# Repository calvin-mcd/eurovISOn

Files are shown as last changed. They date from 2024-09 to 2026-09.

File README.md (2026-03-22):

# eurovISOn
 
40% keyboard designed by some weird Europeans from the 40s discord. It's a qaz-like with special character cluster, exploded ISO with rgb (because why not!?), a macro column to the left and rotary and oled support. It sports a rp2040 and uses a pico Daughterboard for the usb port.

The case is being designed by Haizeus from [haikey](https://www.haikey.design/) and is inspired by the float65. Case design is not finished.

Disclaimer: 
**this is a work in progress project, do not use any of its files**

## Layout

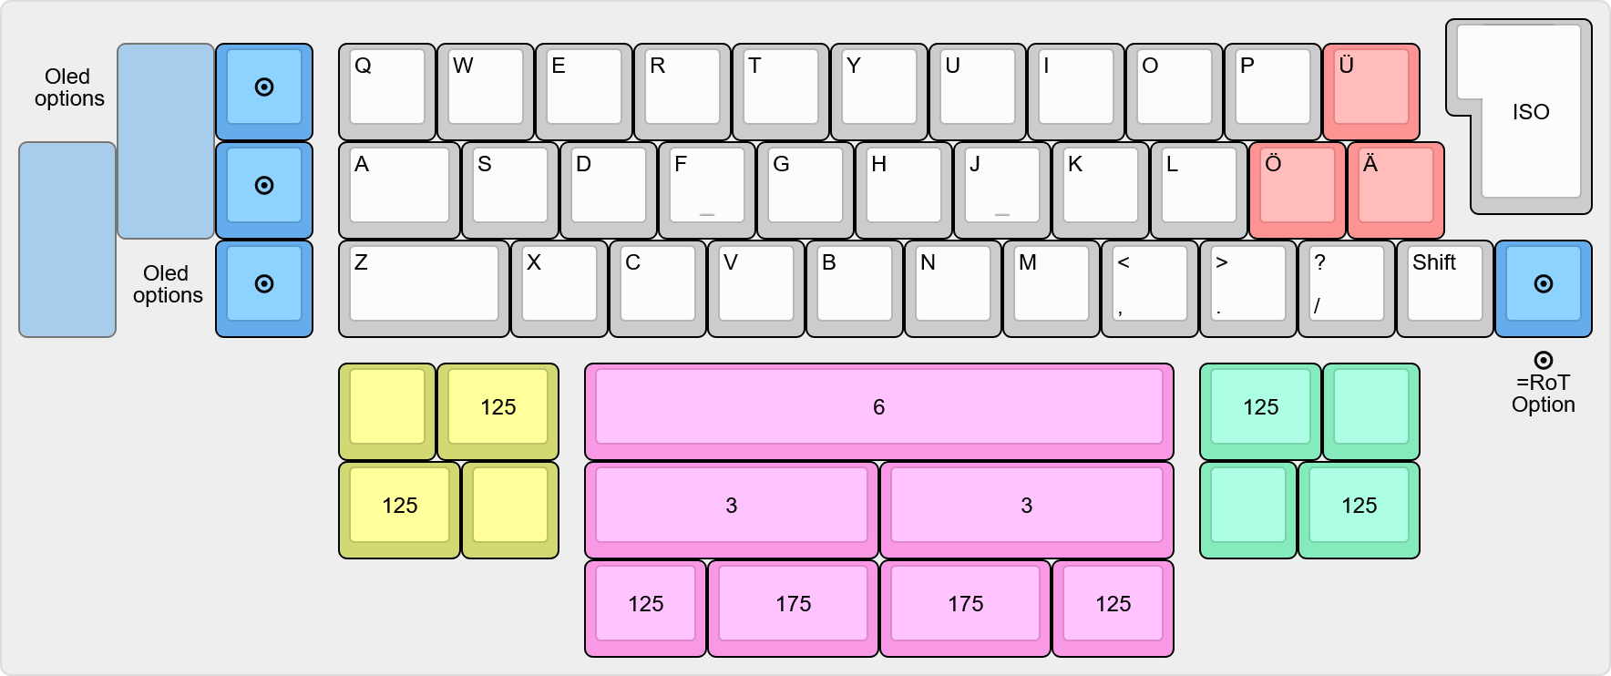
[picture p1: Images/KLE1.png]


[Link](https://www.keyboard-layout-editor.com/#/gists/c5cb8d03115bd811b00f9896965940d2)
**the KLE gist is outdated, refer to the screen above**

## Pictures

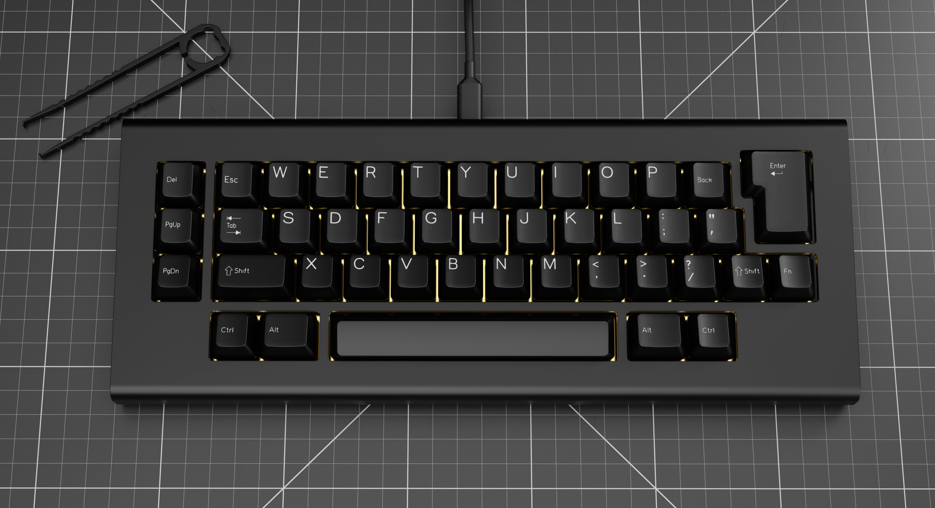
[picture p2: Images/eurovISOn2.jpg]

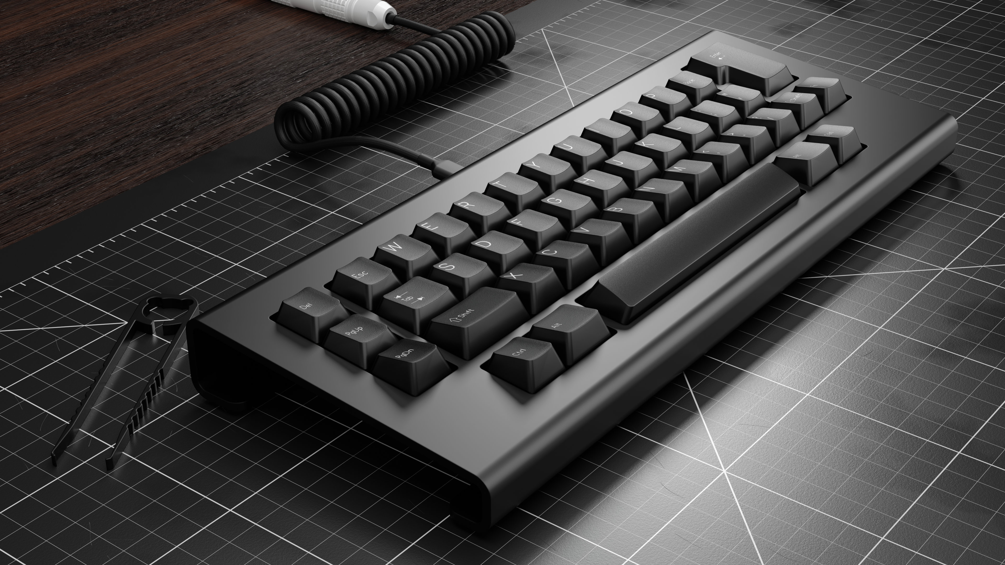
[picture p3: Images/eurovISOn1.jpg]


## Todo

- [ ] make fresh gerber files & bom, pos
- [ ] make firmeware
- [ ] order and test proto pcbs
- [ ] finish case design
- [ ] order and test proto case

## Disclaimer

Please note that this project is a work in progress with no guarantees of a working outcome. No-one involved in this project is responsible for any usage issues that may arise. However, feel free to edit, modify and otherwise utilise these files.

## License

This project is released under the GPL v3 License. Please refer to the LICENCE file.

## Credits
	
As always big thanks to the many people who helped me and inspired this board!

Any questions, contact Calvin0563 on Discord.

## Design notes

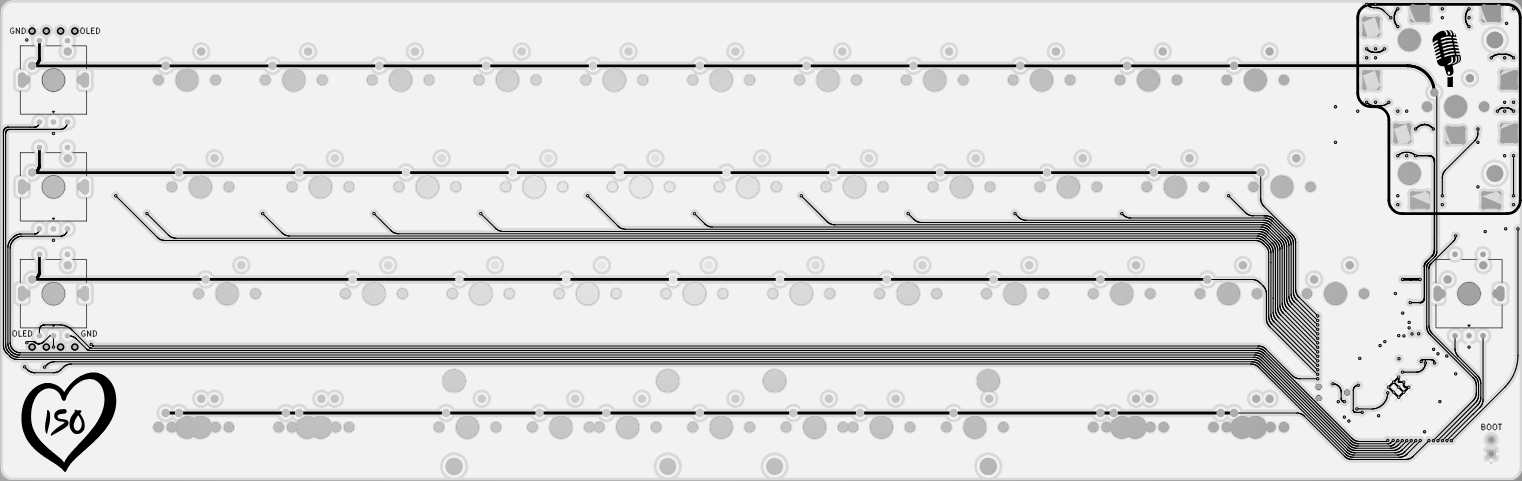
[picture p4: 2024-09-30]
Images/top.png

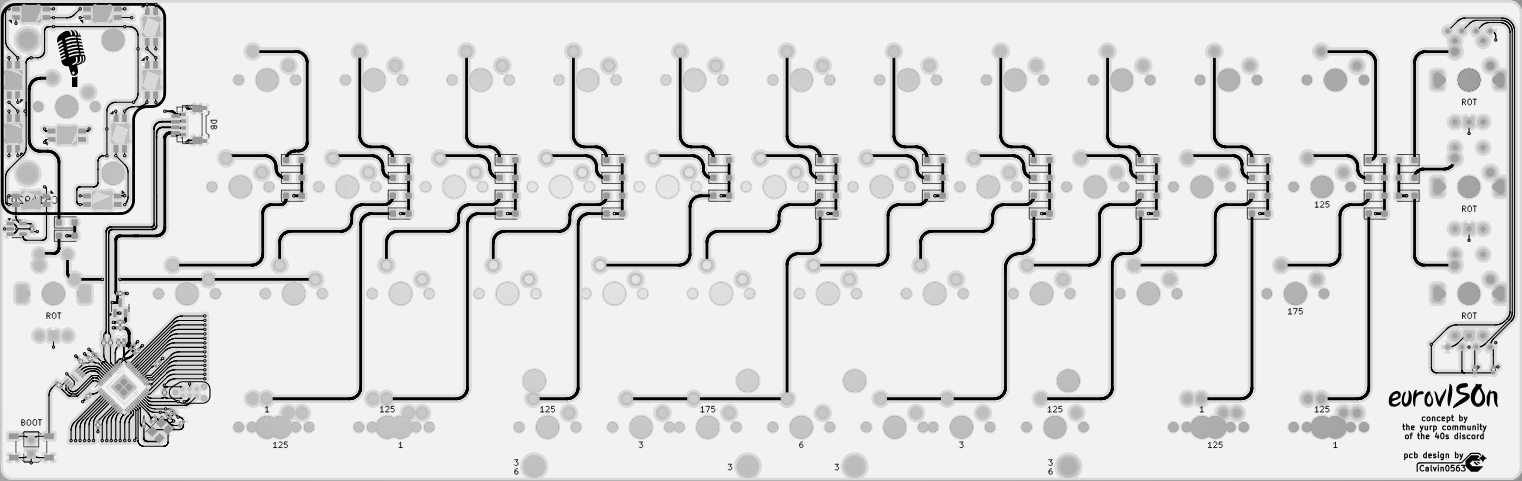
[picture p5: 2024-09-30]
Images/bottom.png

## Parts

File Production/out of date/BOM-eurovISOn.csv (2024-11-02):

Comment | Designator | Footprint | LCSC
boot | SW1 | SW_SPST_TL3342 | C115351
1k | R1,R6 | R_0402_1005Metric | C11702
100nF | C1,C10,C11,C12,C13,C14,C15,C18,C5,C6,C9 | C_0402_1005Metric | C1525
10uF | C7 | C_0402_1005Metric | C15525
22pF | C2,C3 | C_0402_1005Metric | C1555
RP2040 | U3 | RP2040-QFN-56 | C2040
27R | R4,R5 | R_0402_1005Metric | C25190
1k | R9 | R_0402_1005Metric | C25543
4.7k | R10,R8 | R_0402_1005Metric | C25900
W25Q16JVUXIQ | IC1 | SON50P300X200X60-9N | C2843335
SK6812MINI-E | LED1,LED10,LED2,LED3,LED4,LED5,LED6,LED7,LED8,LED9 | LED_6028R | C5149201
1uF | C16,C17,C4,C8 | C_0402_1005Metric | C52923
XC6206PxxxMR-Regulator_Linear | U4 | SOT-23 | C5446
Pico EZmate | J3 | Molex_Pico-EZmate_78171-0004_1x04-1MP_P1.20mm_Vertical | C588524
D_Small | D1,D10,D11,D12,D13,D14,D15,D16,D17,D18,D19,D2,D20,D21,D22,D23,D24,D25,D26,D27,D28,D29,D3,D30,D31,D32,D33,D34,D35,D36,D37,D38,D39,D4,D40,D41,D42,D43,D44,D45,D46,D5,D6,D7,D8,D9 | D_SOD-123F | C81598
74AHCT1G125 | U1 | TSOT-23-5 | C842287
12MHz | Y1 | Crystal_SMD_3225-4Pin_3.2x2.5mm | C9002
JST SH | J2 | JST_SH_SM04B-SRSS-TB_1x04-1MP_P1.00mm_Horizontal

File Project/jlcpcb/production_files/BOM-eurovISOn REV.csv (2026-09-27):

Comment | Designator | Footprint | LCSC | Quantity
100n | C18 | C_0402_1005Metric | C1525 | 1
100nF | C1,C10,C11,C12,C13,C14,C15,C5,C6,C9 | C_0402_1005Metric | C1525 | 10
10uF | C7 | C_0402_1005Metric | C15525 | 1
12MHz | Y1 | Crystal_SMD_3225-4Pin_3.2x2.5mm | C9002 | 1
1k | R1,R6 | R_0402_1005Metric | C11702 | 2
1k | R9 | R_0402_1005Metric | C25543 | 1
1uF | C16,C17,C4,C8 | C_0402_1005Metric | C52923 | 4
22pF | C2,C3 | C_0402_1005Metric | C1555 | 2
27R | R4,R5 | R_0402_1005Metric | C25190 | 2
4.7k | R10,R8 | R_0402_1005Metric | C25900 | 2
500mA | F1 | Fuse_1206_3216Metric | C70076 | 1
5k1 | R2,R3 | R_0402_1005Metric | C25905 | 2
74AHCT1G125 | U1 | TSOT-23-5 | C842287 | 1
D_Small | D1,D10,D11,D12,D13,D14,D15,D16,D17,D18,D19,D2,D20,D21,D22,D23,D24,D25,D26,D27,D28,D29,D3,D30,D31,D32,D33,D34,D35,D36,D37,D38,D39,D4,D40,D41,D42,D43,D44,D45,D46,D5,D6,D7,D8,D9 | D_SOD-123F | C81598 | 46
MX_SK6812MINI-E | LED10 | LED_MX_6028R | C5149201 | 1
PRTR5V0U2X | U5 | SOT-143 | C2827688 | 1
Pico EZmate | J3 | Molex_Pico-EZmate_78171-0004_1x04-1MP_P1.20mm_Vertical | C588524 | 1
RP2040 | U3 | RP2040-QFN-56 | C2040 | 1
SK6812MINI-E | LED1,LED2,LED3,LED4,LED5,LED6,LED7,LED8,LED9 | LED_6028R | C5149201 | 9
USB_C_Receptacle_USB2.0 | J1 | USB_C_Receptacle_HRO_TYPE-C-31-M-12 | C165948 | 1
W25Q16JVUXIQ | IC1 | SON50P300X200X60-9N | C2843335 | 1
XC6206PxxxMR-Regulator_Linear | U4 | SOT-23 | C5446 | 1
boot | SW1 | SW_SPST_TL3342 | C115351 | 1
MX_SW_HS | MX46 | SW_MX_1u |  | 1
MX_SW_HS | MX45 | SW_MX_1.25u |  | 1
MX_SW_HS | MX44 | SW_MX_1.25u |  | 1
MX_SW_HS | MX43 | SW_MX_1.75u |  | 1
MX_SW_HS | MX42 | SW_MX_1.75u |  | 1
MX_SW_HS | MX41 | SW_MX_1.25u |  | 1
MX_SW_HS | MX40 | SW_MX_1u |  | 1
MX_SW_HS | MX39 | SW_MX_1.25u |  | 1
MX_SW_HS | MX38 | SW_MX_1u |  | 1
MX_SW_HS | MX37 | SW_MX_1u |  | 1
MX_SW_HS | MX36 | SW_MX_1u |  | 1
MX_SW_HS | MX35 | SW_MX_1u |  | 1
MX_SW_HS | MX34 | SW_MX_1u |  | 1
MX_SW_HS | MX33 | SW_MX_1u |  | 1
MX_SW_HS | MX32 | SW_MX_1u |  | 1
MX_SW_HS | MX31 | SW_MX_1u |  | 1
MX_SW_HS | MX30 | SW_MX_1u |  | 1
MX_SW_HS | MX29 | SW_MX_1u |  | 1
MX_SW_HS | MX28 | SW_MX_1u |  | 1
MX_SW_HS | MX27 | SW_MX_1.75u |  | 1
MX_SW_HS | MX26 | SW_MX_1u |  | 1
MX_SW_HS | MX25 | SW_MX_1u |  | 1
MX_SW_HS | MX24 | SW_MX_1u |  | 1
MX_SW_HS | MX23 | SW_MX_1u |  | 1
MX_SW_HS | MX22 | SW_MX_1u |  | 1
MX_SW_HS | MX21 | SW_MX_1u |  | 1
MX_SW_HS | MX20 | SW_MX_1u |  | 1
MX_SW_HS | MX19 | SW_MX_1u |  | 1
MX_SW_HS | MX18 | SW_MX_1u |  | 1
MX_SW_HS | MX17 | SW_MX_1u |  | 1
MX_SW_HS | MX16 | SW_MX_1u |  | 1
MX_SW_HS | MX15 | SW_MX_1.25u |  | 1
MX_SW_HS | MX14 | SW_MX_1u |  | 1
MX_SW_HS | MX13 | SW_MX_1u |  | 1
MX_SW_HS | MX12 | SW_MX_1u |  | 1
MX_SW_HS | MX11 | SW_MX_1u |  | 1
MX_SW_HS | MX10 | SW_MX_1u |  | 1
MX_SW_HS | MX9 | SW_MX_1u |  | 1
MX_SW_HS | MX8 | SW_MX_1u |  | 1
MX_SW_HS | MX7 | SW_MX_1u |  | 1
MX_SW_HS | MX6 | SW_MX_1u |  | 1
MX_SW_HS | MX5 | SW_MX_1u |  | 1
MX_SW_HS | MX4 | SW_MX_1u |  | 1
MX_SW_HS | MX3 | SW_MX_1u |  | 1
MX_SW_HS | MX2 | SW_MX_1u |  | 1
MX_SW_HS | MX1 | SW_MX_1u |  | 1
MX_SW_HS | MX49 | SW_MX_1u |  | 1
OLED | OL2 | OLED_v2 |  | 1
MX_SW_HS | MX51 | SW_MX_1u |  | 1
MX_stab | S1 | STAB_MX_P_ISO-ROT |  | 1
MX_SW_HS | MX48 | SW_MX_1.25u |  | 1
RotaryEncoder_Switch | SW3 | ROT_Alps_EC11E-Switch |  | 1
RotaryEncoder_Switch | SW6 | ROT_Alps_EC11E-Switch |  | 1
MX_SW_HS | MX52 | SW_MX_1.25u |  | 1
MX_stab | S3 | STAB_MX_P_3u |  | 1
MX_SW_HS | MX53 | SW_MX_1u |  | 1
MX_SW_HS | MX47 | SW_MX_1u |  | 1
RotaryEncoder_Switch | SW4 | ROT_Alps_EC11E-Switch |  | 1
MX_SW_HS | MX50 | SW_MX_1u |  | 1
MX_stab | S2 | STAB_MX_P_3u |  | 1
OLED | OL1 | OLED_v2 |  | 1
MX_stab | S4 | STAB_MX_P_6u |  | 1
RotaryEncoder_Switch | SW5 | ROT_Alps_EC11E-Switch |  | 1
JST SH | J2 | JST_SH_SM04B-SRSS-TB_1x04-1MP_P1.00mm_Horizontal |  | 1
SK6812MINI-E | LED11 | LED_6028R |  | 1
SK6812MINI-E | LED12 | LED_6028R |  | 1
SK6812MINI-E | LED14 | LED_6028R |  | 1
SK6812MINI-E | LED13 | LED_6028R |  | 1

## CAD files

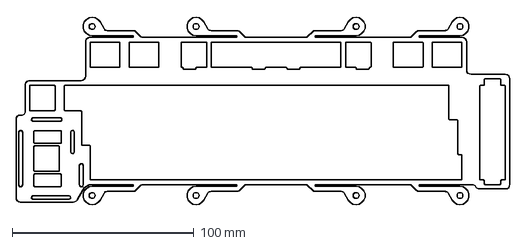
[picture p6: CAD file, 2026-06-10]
Production/case/eurovison half plate.dxf
271.6 x 104.0 mm

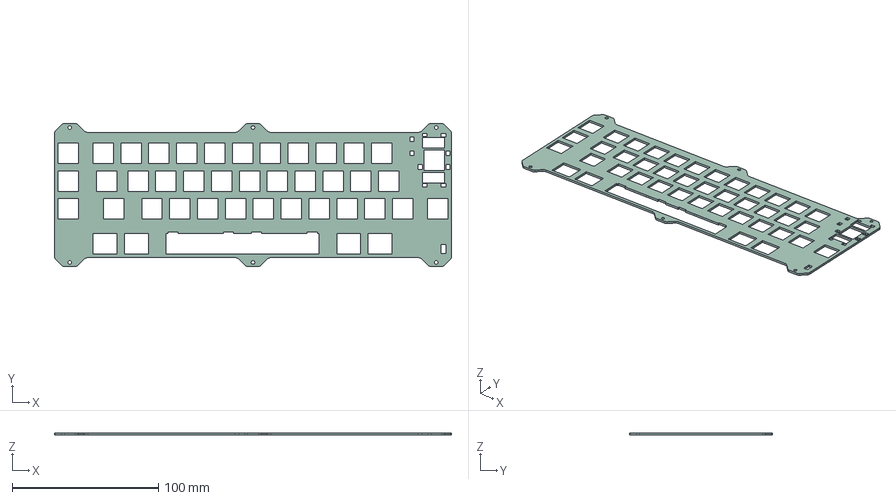
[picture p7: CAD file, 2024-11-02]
Production/out of date/plate.step
271.5 x 97.7 x 1.60 mm

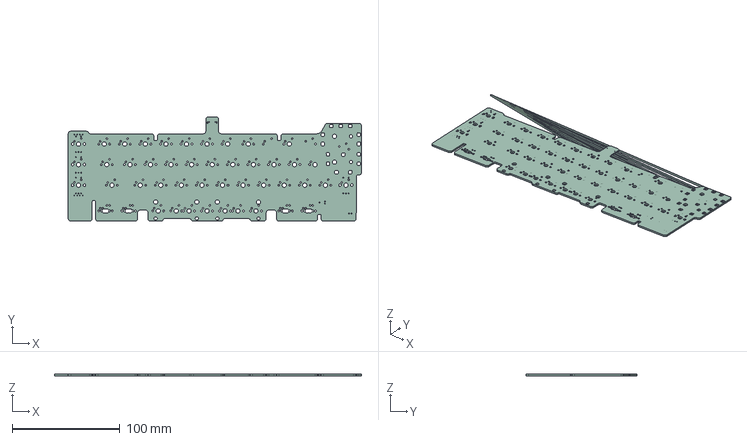
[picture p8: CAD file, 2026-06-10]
Project/eurovISOn revision FINAL no rgb.step
284.3 x 103.2 x 1.51 mm

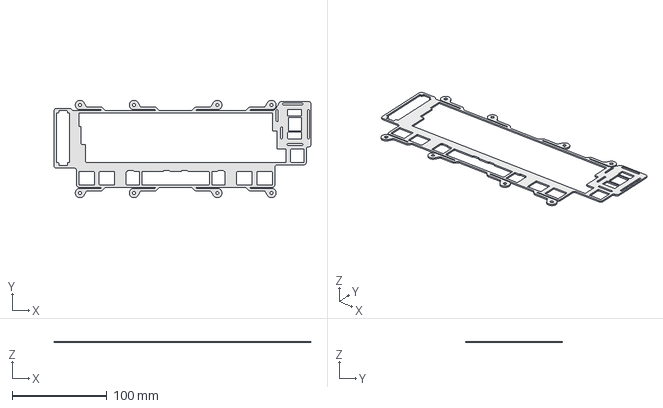
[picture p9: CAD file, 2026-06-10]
Production/case/eurovISOn metal plate.step
271.6 x 102.9 x 1.50 mm

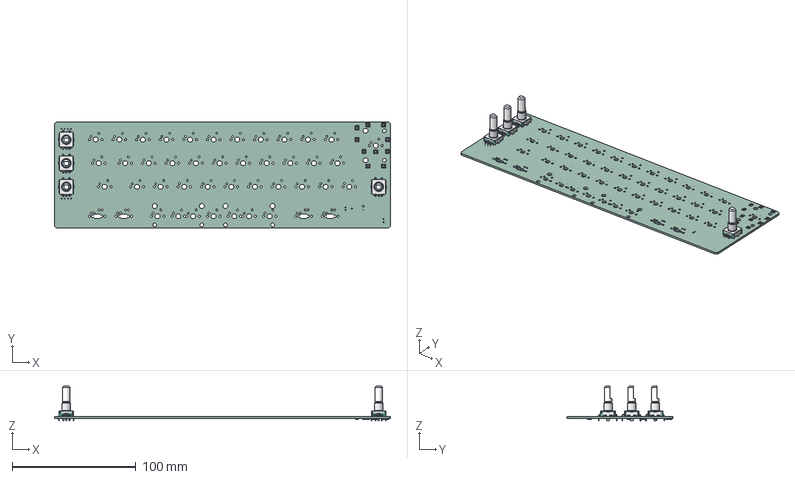
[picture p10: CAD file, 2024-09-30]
Production/out of date/eurovISOn.step
271.5 x 85.7 x 28.2 mm
(Unsaved) x 4
LED_SK6812MINI-E v2 x 10
W25X40CLUXIG TR
eurovISOn_PCB

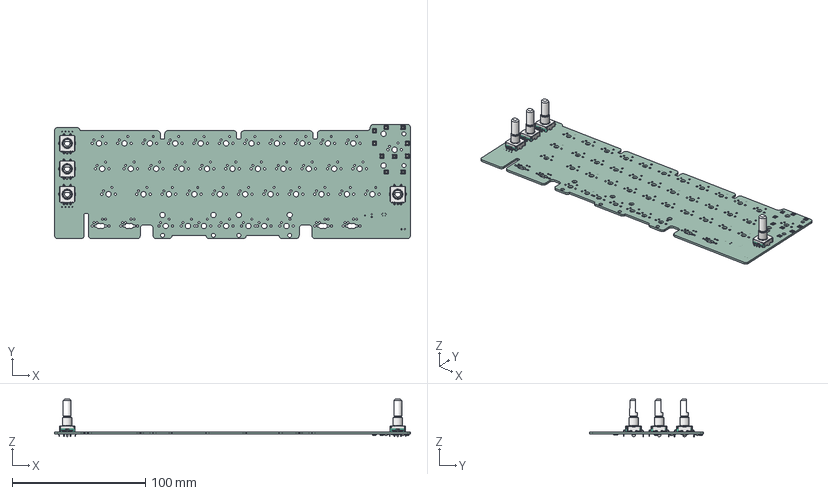
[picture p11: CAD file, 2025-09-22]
Project/eurovISOn REV.step
266.7 x 85.7 x 28.2 mm
(Unsaved) x 4
LED_SK6812MINI-E v2 x 10
W25X40CLUXIG TR
eurovISOn REV_PCB

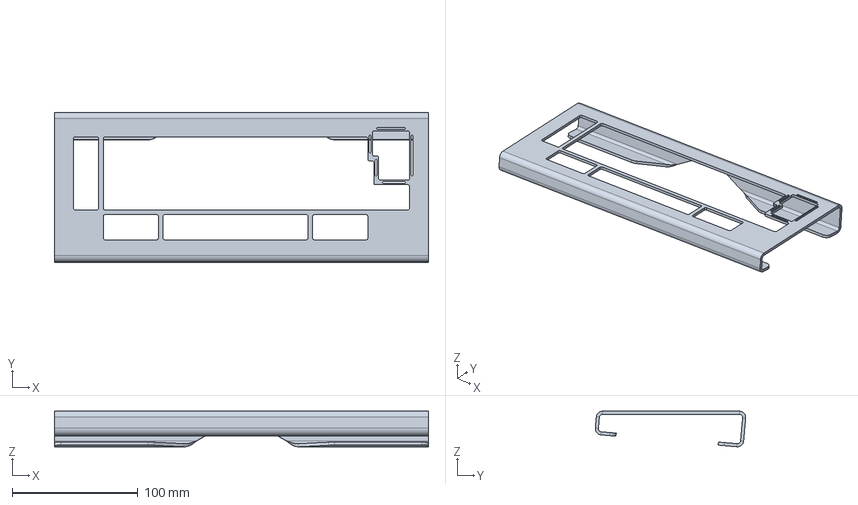
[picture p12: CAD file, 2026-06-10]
Production/case/eurovISOn bent case.step
297.8 x 119.7 x 28.4 mm

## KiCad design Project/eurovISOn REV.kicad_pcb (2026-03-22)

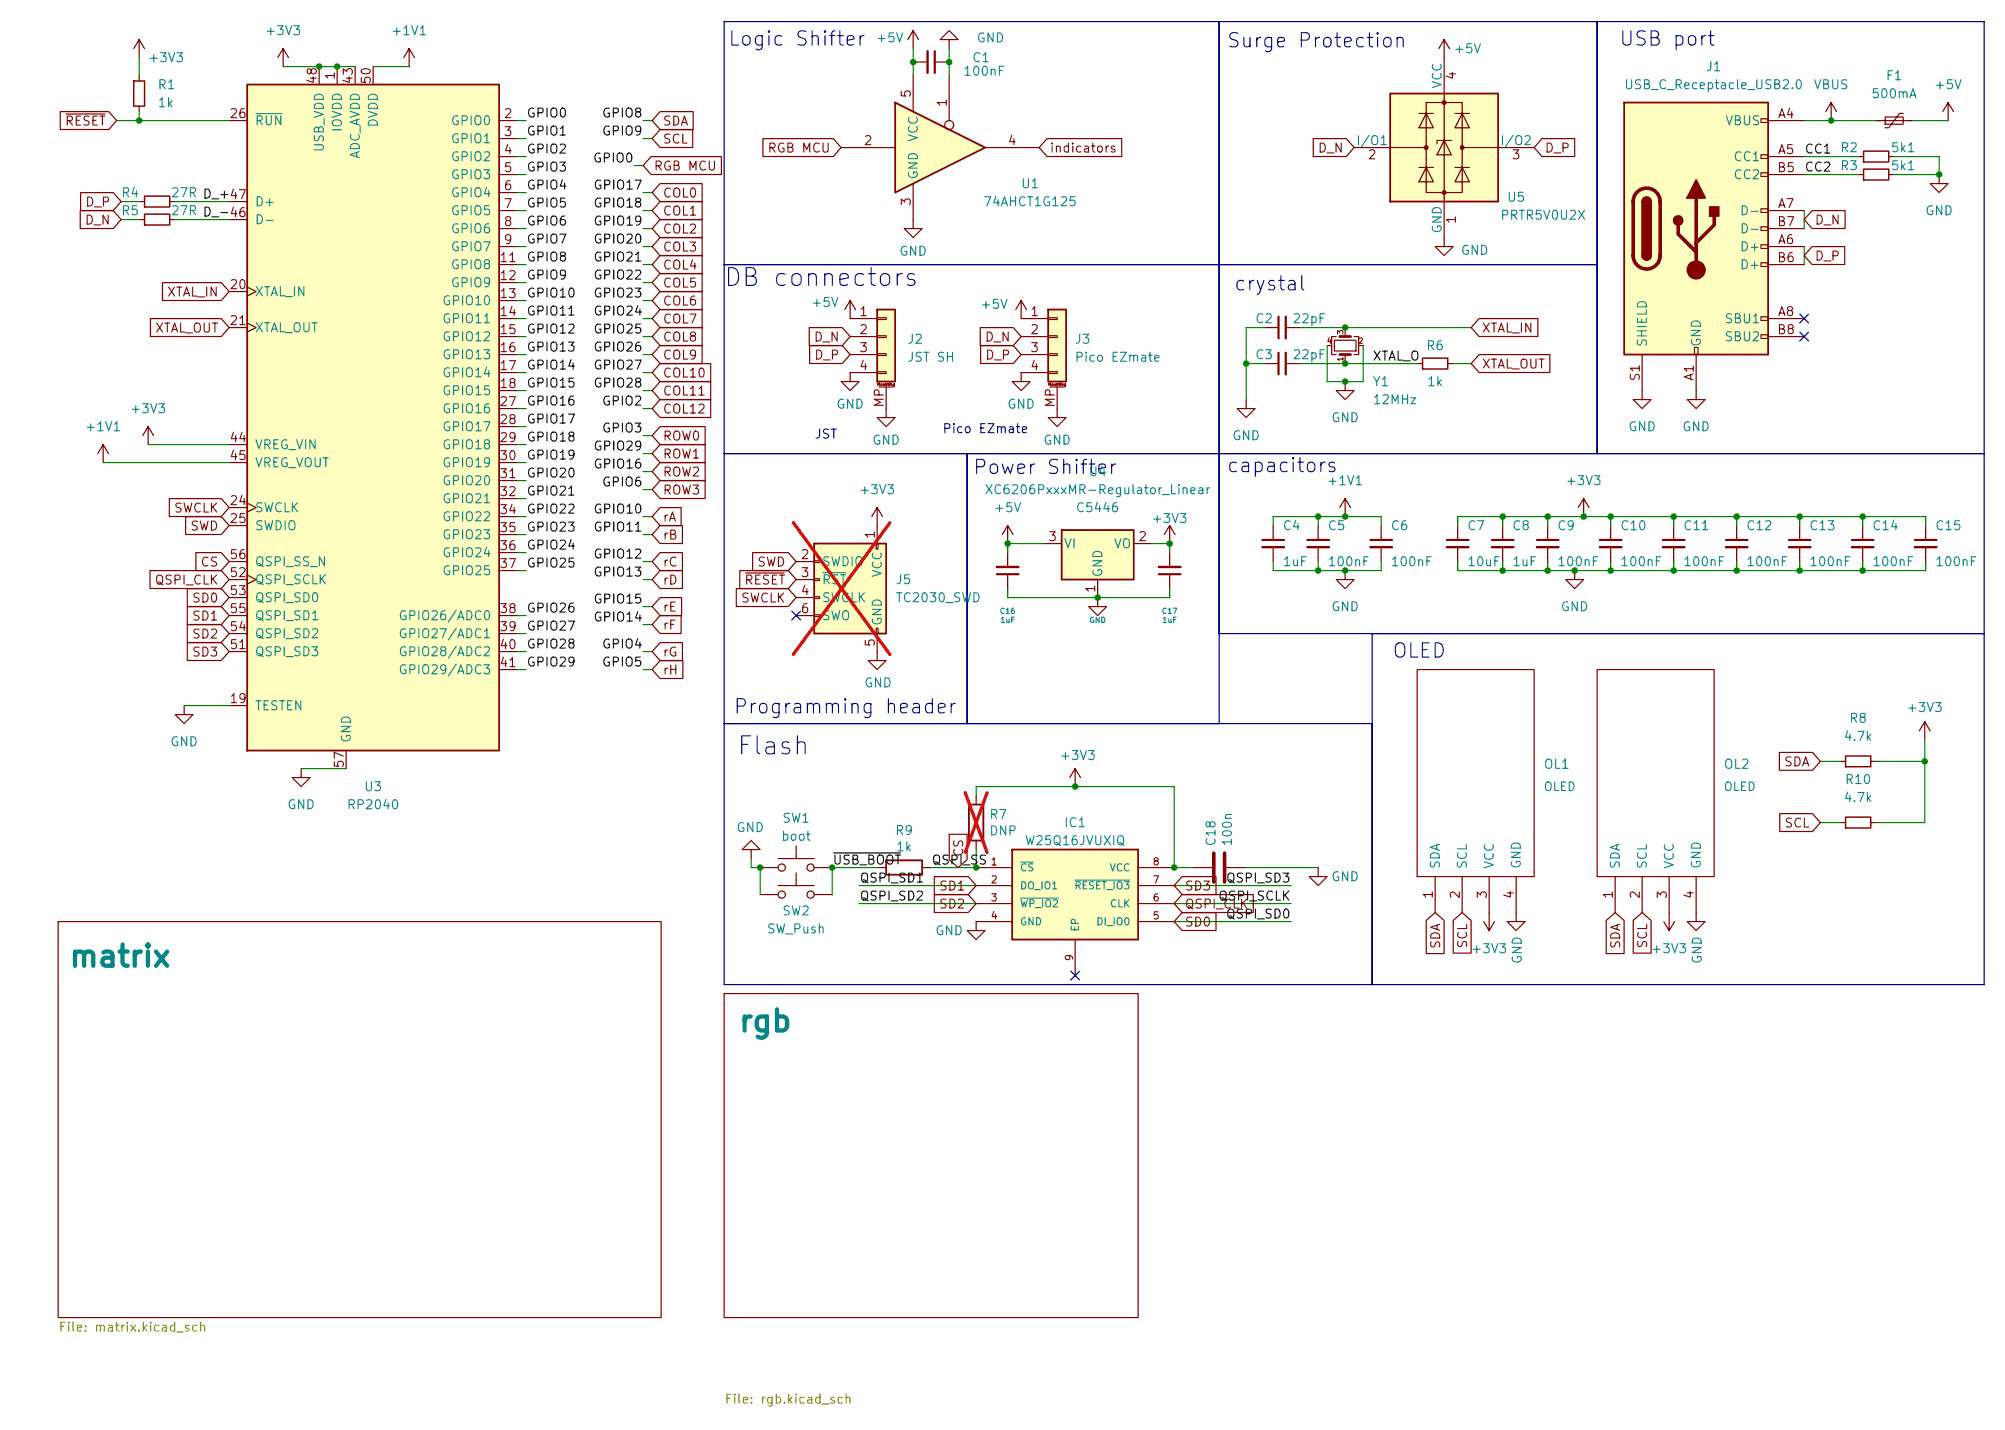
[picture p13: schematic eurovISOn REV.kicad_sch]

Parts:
C1: 100nF; C_0402_1005Metric
C2, C3: 22pF; C_0402_1005Metric; LCSC C1555
C4, C8, C16, C17: 1uF; C_0402_1005Metric; LCSC C52923
C5, C6, C9, C10, C11, C12, C13, C14, C15: 100nF; C_0402_1005Metric; LCSC C1525
C7: 10uF; C_0402_1005Metric; LCSC C15525
C18: 100n; C_0402_1005Metric; LCSC C1525
F1: 500mA; Fuse_1206_3216Metric; LCSC C70076
IC1: W25Q16JVUXIQ; SON50P300X200X60-9N; MANUFACTURER_PART_NUMBER W25Q16JVUXIQ; LCSC Part C2843335
J1: USB_C_Receptacle_USB2.0; USB_C_Receptacle_HRO_TYPE-C-31-M-12; LCSC C165948
J2: JST SH; JST_SH_SM04B-SRSS-TB_1x04-1MP_P1.00mm_Horizontal
J3: Pico EZmate; Molex_Pico-EZmate_78171-0004_1x04-1MP_P1.20mm_Vertical
J5: TC2030_SWD; CON_TC2030_outlined; not fitted
OL1, OL2: OLED; OLED_v2
R1, R6: 1k; R_0402_1005Metric; LCSC C11702
R2, R3: 5k1; R_0402_1005Metric; LCSC C25905
R4, R5: 27R; R_0402_1005Metric; LCSC C25190
R7: DNP; C_0402_1005Metric; LCSC C25905; not fitted
R8, R10: 4.7k; R_0402_1005Metric; LCSC C25900
R9: 1k; R_0402_1005Metric; LCSC Part C25543
SW1: boot; SW_SPST_TL3342; LCSC Part C115351
SW2: SW_Push; PinSocket_1x02_P2.54mm_Vertical
U1: 74AHCT1G125; TSOT-23-5
U3: RP2040; RP2040-QFN-56; LCSC C2040
U4: XC6206PxxxMR-Regulator_Linear; SOT-23; LCSC C5446
U5: PRTR5V0U2X; SOT-143; LCSC C2827688
Y1: 12MHz; Crystal_SMD_3225-4Pin_3.2x2.5mm; LCSC C9002

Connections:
+1V1: C4.1, C5.1, C6.1, U3.23 (DVDD), U3.45 (VREG_VOUT), U3.50 (DVDD)
+3V3: C7.1, C8.1, C9.1, C10.1, C11.1, C12.1, C13.1, C14.1, C15.1, C17.2, C18.1, IC1.8 (VCC), J5.1 (VCC), OL1.3 (VCC), OL2.3 (VCC), R1.1, R7.1, R8.2, R10.2, U3.1 (IOVDD), U3.10 (IOVDD), U3.22 (IOVDD), U3.33 (IOVDD), U3.42 (IOVDD), U3.43 (ADC_AVDD), U3.44 (VREG_VIN), U3.48 (USB_VDD), U3.49 (IOVDD), U4.2 (VO)
+5V: C1.2, C16.2, F1.2, J2.1, J3.1, U1.5 (VCC), U4.3 (VI), U5.4 (VCC); also elsewhere on the board
/CC1: J1.A5 (CC1), R2.1
/CC2: J1.B5 (CC2), R3.1
/D_+: R4.2, U3.47 (D+)
/D_-: R5.2, U3.46 (D-)
/GPIO1: U3.3 (GPIO1)
/GPIO7: U3.9 (GPIO7)
/XTAL_O: C3.2, R6.1, Y1.1
/~USB_BOOT: R9.2, SW1.2, SW2.2
COL0: U3.28 (GPIO17); also elsewhere on the board
COL1: U3.29 (GPIO18); also elsewhere on the board
COL2: U3.30 (GPIO19); also elsewhere on the board
COL3: U3.31 (GPIO20); also elsewhere on the board
COL4: U3.32 (GPIO21); also elsewhere on the board
COL5: U3.34 (GPIO22); also elsewhere on the board
COL6: U3.35 (GPIO23); also elsewhere on the board
COL7: U3.36 (GPIO24); also elsewhere on the board
COL8: U3.37 (GPIO25); also elsewhere on the board
COL9: U3.38 (GPIO26/ADC0); also elsewhere on the board
COL10: U3.39 (GPIO27/ADC1); also elsewhere on the board
COL11: U3.40 (GPIO28/ADC2); also elsewhere on the board
COL12: U3.4 (GPIO2); also elsewhere on the board
CS: IC1.1 (~CS), R7.2, R9.1, U3.56 (QSPI_SS_N)
D_N: J1.A7 (D-), J1.B7 (D-), J2.2, J3.2, R5.1, U5.2 (I/O1)
D_P: J1.A6 (D+), J1.B6 (D+), J2.3, J3.3, R4.1, U5.3 (I/O2)
GND: C1.1, C2.1, C3.1, C4.2, C5.2, C6.2, C7.2, C8.2, C9.2, C10.2, C11.2, C12.2, C13.2, C14.2, C15.2, C16.1, C17.1, C18.2, IC1.4 (GND), J1.A1 (GND), J1.A12 (GND), J1.B1 (GND), J1.B12 (GND), J1.S1 (SHIELD), J2.4, J2.MP (MountPin), J3.4, J3.MP (MountPin), J5.5 (GND), OL1.4 (GND), OL2.4 (GND), R2.2, R3.2, SW1.1, SW2.1, U1.1, U1.3 (GND), U3.19 (TESTEN), U3.57 (GND), U4.1 (GND), U5.1 (GND), Y1.2, Y1.4; also elsewhere on the board
QSPI_CLK: IC1.6 (CLK), U3.52 (QSPI_SCLK)
RGB MCU: U1.2, U3.2 (GPIO0)
ROW0: U3.5 (GPIO3); also elsewhere on the board
ROW1: U3.41 (GPIO29/ADC3); also elsewhere on the board
ROW2: U3.27 (GPIO16); also elsewhere on the board
ROW3: U3.8 (GPIO6); also elsewhere on the board
SCL: OL1.2 (SCL), OL2.2 (SCL), R10.1, U3.12 (GPIO9)
SD0: IC1.5 (DI_IO0), U3.53 (QSPI_SD0)
SD1: IC1.2 (DO_IO1), U3.55 (QSPI_SD1)
SD2: IC1.3 (~WP_IO2), U3.54 (QSPI_SD2)
SD3: IC1.7 (~RESET_IO3), U3.51 (QSPI_SD3)
SDA: OL1.1 (SDA), OL2.1 (SDA), R8.1, U3.11 (GPIO8)
SWCLK: J5.4 (SWCLK), U3.24 (SWCLK)
SWD: J5.2 (SWDIO), U3.25 (SWDIO)
VBUS: F1.1, J1.A4 (VBUS), J1.A9 (VBUS), J1.B4 (VBUS), J1.B9 (VBUS)
XTAL_IN: C2.2, U3.20 (XTAL_IN), Y1.3
XTAL_OUT: R6.2, U3.21 (XTAL_OUT)
indicators: U1.4; also elsewhere on the board
rA: U3.13 (GPIO10); also elsewhere on the board
rB: U3.14 (GPIO11); also elsewhere on the board
rC: U3.15 (GPIO12); also elsewhere on the board
rD: U3.16 (GPIO13); also elsewhere on the board
rE: U3.18 (GPIO15); also elsewhere on the board
rF: U3.17 (GPIO14); also elsewhere on the board
rG: U3.6 (GPIO4); also elsewhere on the board
rH: U3.7 (GPIO5); also elsewhere on the board
~RESET: J5.3 (~RST), R1.2, U3.26 (~RUN)

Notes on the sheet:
capacitors
Power Shifter
Pico EZmate
OLED
crystal
Logic Shifter
DB connectors
USB port
Flash
Programming header
JST
Surge Protection

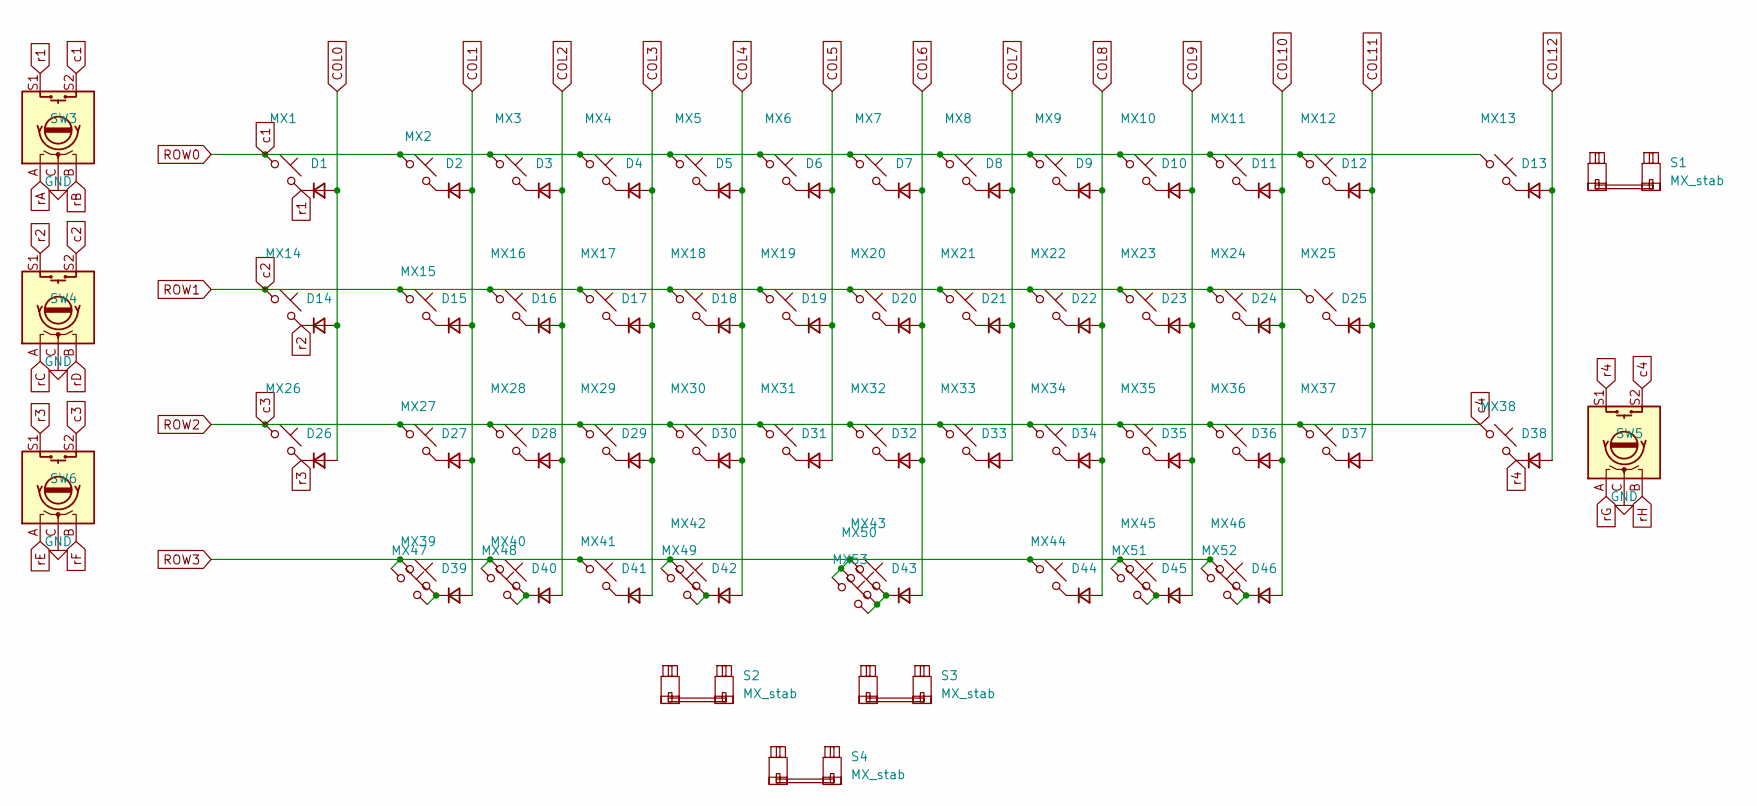
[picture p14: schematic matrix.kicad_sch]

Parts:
D1, D2, D3, D4, D5, D6, D7, D8, D9, D10, D11, D12, D13, D14, D15, D16, D17, D18, D19, D20, D21, D22, D23, D24, D25, D26, D27, D28, D29, D30, D31, D32, D33, D34, D35, D36, D37, D38, D39, D40, D41, D42, D43, D44, D45, D46: D_Small; D_SOD-123F
MX1, MX2, MX3, MX4, MX5, MX6, MX7, MX8, MX9, MX10, MX11, MX12, MX13, MX14, MX16, MX17, MX18, MX19, MX20, MX21, MX22, MX23, MX24, MX25, MX26, MX28, MX29, MX30, MX31, MX32, MX33, MX34, MX35, MX36, MX37, MX38, MX40, MX46, MX47, MX49, MX50, MX51, MX53: MX_SW_HS; SW_MX_1u
MX15, MX39, MX41, MX44, MX45, MX48, MX52: MX_SW_HS; SW_MX_1.25u
MX27, MX42, MX43: MX_SW_HS; SW_MX_1.75u
S1: MX_stab; STAB_MX_P_ISO-ROT
S2, S3: MX_stab; STAB_MX_P_3u
S4: MX_stab; STAB_MX_P_6u
SW3, SW4, SW5, SW6: RotaryEncoder_Switch; ROT_Alps_EC11E-Switch

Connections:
COL0: D1.2 (A), D14.2 (A), D26.2 (A); also elsewhere on the board
COL1: D2.2 (A), D15.2 (A), D27.2 (A), D39.2 (A); also elsewhere on the board
COL2: D3.2 (A), D16.2 (A), D28.2 (A), D40.2 (A); also elsewhere on the board
COL3: D4.2 (A), D17.2 (A), D29.2 (A), D41.2 (A); also elsewhere on the board
COL4: D5.2 (A), D18.2 (A), D30.2 (A), D42.2 (A); also elsewhere on the board
COL5: D6.2 (A), D19.2 (A), D31.2 (A); also elsewhere on the board
COL6: D7.2 (A), D20.2 (A), D32.2 (A), D43.2 (A); also elsewhere on the board
COL7: D8.2 (A), D21.2 (A), D33.2 (A); also elsewhere on the board
COL8: D9.2 (A), D22.2 (A), D34.2 (A), D44.2 (A); also elsewhere on the board
COL9: D10.2 (A), D23.2 (A), D35.2 (A), D45.2 (A); also elsewhere on the board
COL10: D11.2 (A), D24.2 (A), D36.2 (A), D46.2 (A); also elsewhere on the board
COL11: D12.2 (A), D25.2 (A), D37.2 (A); also elsewhere on the board
COL12: D13.2 (A), D38.2 (A); also elsewhere on the board
GND: SW3.C, SW4.C, SW5.C, SW6.C; also elsewhere on the board
unnamed: D2.1 (K), MX2.2
unnamed: D3.1 (K), MX3.2
unnamed: D4.1 (K), MX4.2
unnamed: D5.1 (K), MX5.2
unnamed: D6.1 (K), MX6.2
unnamed: D7.1 (K), MX7.2
unnamed: D8.1 (K), MX8.2
unnamed: D9.1 (K), MX9.2
unnamed: D10.1 (K), MX10.2
unnamed: D11.1 (K), MX11.2
unnamed: D12.1 (K), MX12.2
unnamed: D13.1 (K), MX13.2
unnamed: D15.1 (K), MX15.2
unnamed: D16.1 (K), MX16.2
unnamed: D17.1 (K), MX17.2
unnamed: D18.1 (K), MX18.2
unnamed: D19.1 (K), MX19.2
unnamed: D20.1 (K), MX20.2
unnamed: D21.1 (K), MX21.2
unnamed: D22.1 (K), MX22.2
unnamed: D23.1 (K), MX23.2
unnamed: D24.1 (K), MX24.2
unnamed: D25.1 (K), MX25.2
unnamed: D27.1 (K), MX27.2
unnamed: D28.1 (K), MX28.2
unnamed: D29.1 (K), MX29.2
unnamed: D30.1 (K), MX30.2
unnamed: D31.1 (K), MX31.2
unnamed: D32.1 (K), MX32.2
unnamed: D33.1 (K), MX33.2
unnamed: D34.1 (K), MX34.2
unnamed: D35.1 (K), MX35.2
unnamed: D36.1 (K), MX36.2
unnamed: D37.1 (K), MX37.2
unnamed: D39.1 (K), MX39.2, MX47.2
unnamed: D40.1 (K), MX40.2, MX48.2
unnamed: D41.1 (K), MX41.2
unnamed: D42.1 (K), MX42.2, MX49.2
unnamed: D43.1 (K), MX43.2, MX50.2, MX53.2
unnamed: D44.1 (K), MX44.2
unnamed: D45.1 (K), MX45.2, MX51.2
unnamed: D46.1 (K), MX46.2, MX52.2
ROW0: MX1.1, MX2.1, MX3.1, MX4.1, MX5.1, MX6.1, MX7.1, MX8.1, MX9.1, MX10.1, MX11.1, MX12.1, MX13.1, SW3.S2; also elsewhere on the board
ROW1: MX14.1, MX15.1, MX16.1, MX17.1, MX18.1, MX19.1, MX20.1, MX21.1, MX22.1, MX23.1, MX24.1, MX25.1, SW4.S2; also elsewhere on the board
ROW2: MX26.1, MX27.1, MX28.1, MX29.1, MX30.1, MX31.1, MX32.1, MX33.1, MX34.1, MX35.1, MX36.1, MX37.1, MX38.1, SW5.S2, SW6.S2; also elsewhere on the board
ROW3: MX39.1, MX40.1, MX41.1, MX42.1, MX43.1, MX44.1, MX45.1, MX46.1, MX47.1, MX48.1, MX49.1, MX50.1, MX51.1, MX52.1, MX53.1; also elsewhere on the board
r1: D1.1 (K), MX1.2, SW3.S1
r2: D14.1 (K), MX14.2, SW4.S1
r3: D26.1 (K), MX26.2, SW6.S1
r4: D38.1 (K), MX38.2, SW5.S1
rA: SW3.A; also elsewhere on the board
rB: SW3.B; also elsewhere on the board
rC: SW4.A; also elsewhere on the board
rD: SW4.B; also elsewhere on the board
rE: SW6.A; also elsewhere on the board
rF: SW6.B; also elsewhere on the board
rG: SW5.A; also elsewhere on the board
rH: SW5.B; also elsewhere on the board

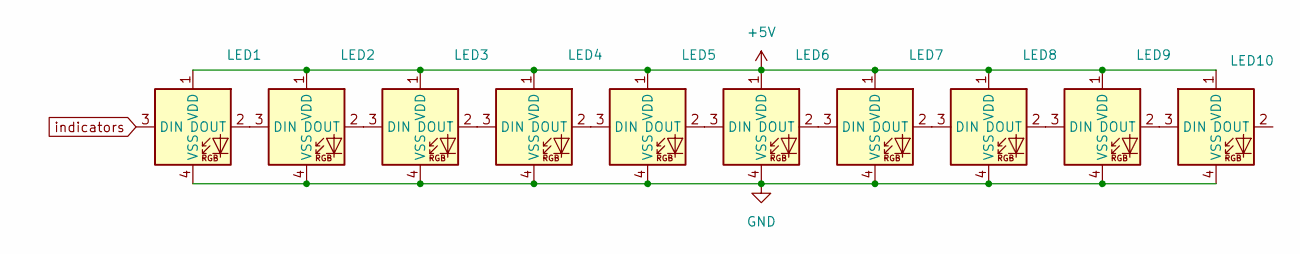
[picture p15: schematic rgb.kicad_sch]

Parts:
LED1, LED2, LED3, LED4, LED5, LED6, LED7, LED8, LED9: SK6812MINI-E; LED_6028R
LED10: MX_SK6812MINI-E; LED_MX_6028R

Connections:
+5V: LED1.1 (VDD), LED2.1 (VDD), LED3.1 (VDD), LED4.1 (VDD), LED5.1 (VDD), LED6.1 (VDD), LED7.1 (VDD), LED8.1 (VDD), LED9.1 (VDD), LED10.1 (VDD); also elsewhere on the board
GND: LED1.4 (VSS), LED2.4 (VSS), LED3.4 (VSS), LED4.4 (VSS), LED5.4 (VSS), LED6.4 (VSS), LED7.4 (VSS), LED8.4 (VSS), LED9.4 (VSS), LED10.4 (VSS); also elsewhere on the board
unnamed: LED1.2 (DOUT), LED2.3 (DIN)
unnamed: LED2.2 (DOUT), LED3.3 (DIN)
unnamed: LED3.2 (DOUT), LED4.3 (DIN)
unnamed: LED4.2 (DOUT), LED5.3 (DIN)
unnamed: LED5.2 (DOUT), LED6.3 (DIN)
unnamed: LED6.2 (DOUT), LED7.3 (DIN)
unnamed: LED7.2 (DOUT), LED8.3 (DIN)
unnamed: LED8.2 (DOUT), LED9.3 (DIN)
unnamed: LED9.2 (DOUT), LED10.3 (DIN)
indicators: LED1.3 (DIN); also elsewhere on the board

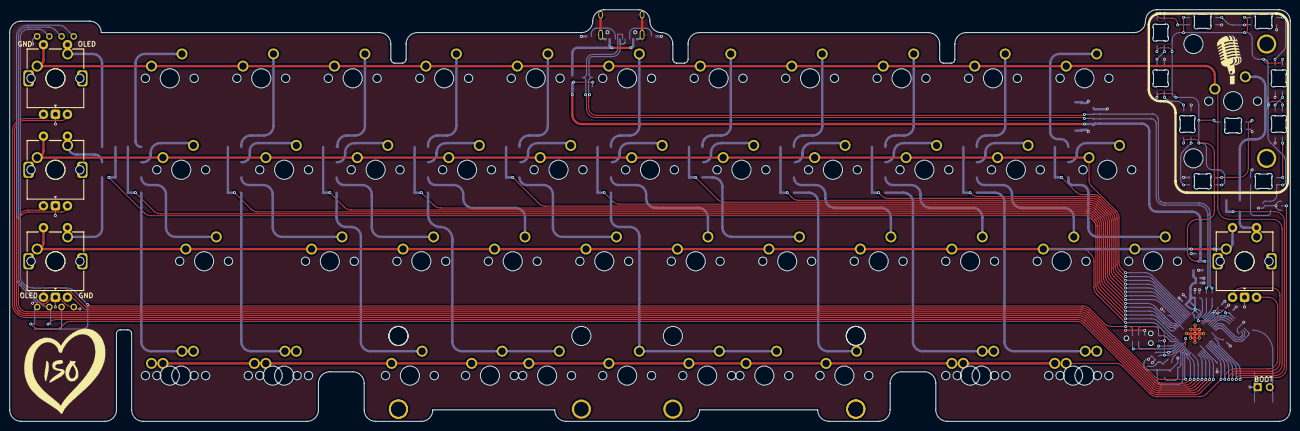
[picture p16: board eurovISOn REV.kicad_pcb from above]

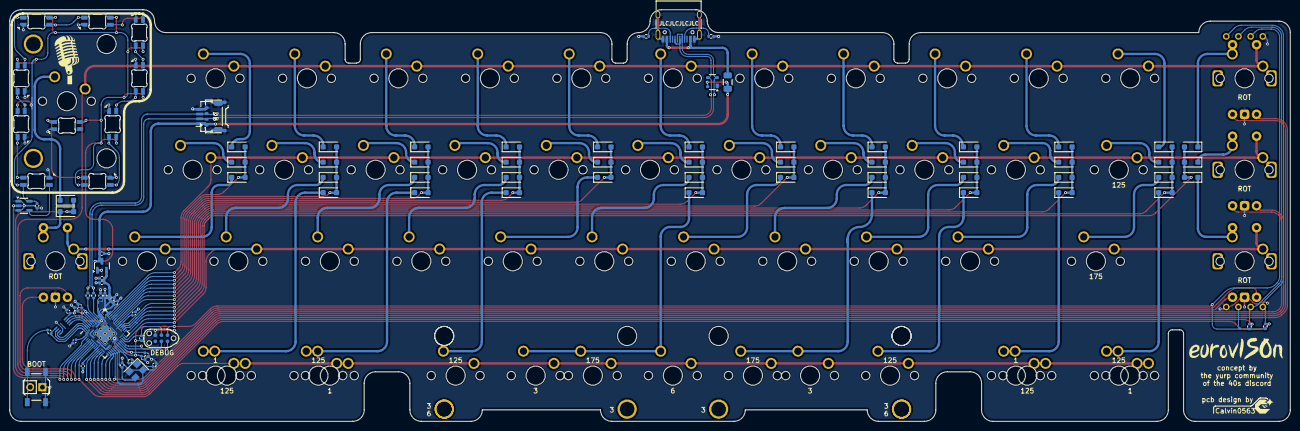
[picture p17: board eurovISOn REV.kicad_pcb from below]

Board: 2 copper layers, 266.7 x 85.7 mm, 159 parts (96 on the bottom side), 108 nets.

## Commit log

2024-09-30 update project
    [BOM-eurovISOn.csv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]
2024-11-02 final revision
    [BOM-eurovISOn.csv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]
2025-11-23 rev wip
    usb port added
    [eurovISOn REV-B_Cu.gbr, eurovISOn REV-B_Mask.gbr, eurovISOn REV-B_Paste.gbr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]
2026-03-22 readme update
    [eurovISOn REV.kicad_pcb]
2026-04-11 centered usb port and longer tab for case fitment
    [eurovISOn REV-B_Cu.gbr, eurovISOn REV-B_Mask.gbr, eurovISOn REV-B_Paste.gbr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]
2026-04-19 pcb clean up
    [eurovISOn REV-B_Cu.gbr, eurovISOn REV-B_Mask.gbr, eurovISOn REV-B_Paste.gbr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]
2026-04-19 kicad 9
2026-05-31 rgb positions
    [eurovISOn REV-B_Cu.gbr, eurovISOn REV-B_Mask.gbr, eurovISOn REV-B_Paste.gbr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]
2026-06-10 pcb update
    production files (lacking pos,bom)
    [BOM-eurovISOn.csv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]
